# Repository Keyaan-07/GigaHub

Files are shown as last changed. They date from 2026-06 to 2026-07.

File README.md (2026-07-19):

# GigaHub
GigaHub is a USB 3.0 Hub capable of speeds upto 5Gbps. It comes in a small form factor and can handle upto 4 devices simultaneously. The silkscreen on the bottom makes it obvious. You plug in the USB-C cable on one side, and you get 4x USB-C cables. 

I made this project just for fun and because i had some free time. I could've made USB 2.0 hub but this was a bit challenging thus i made this!!

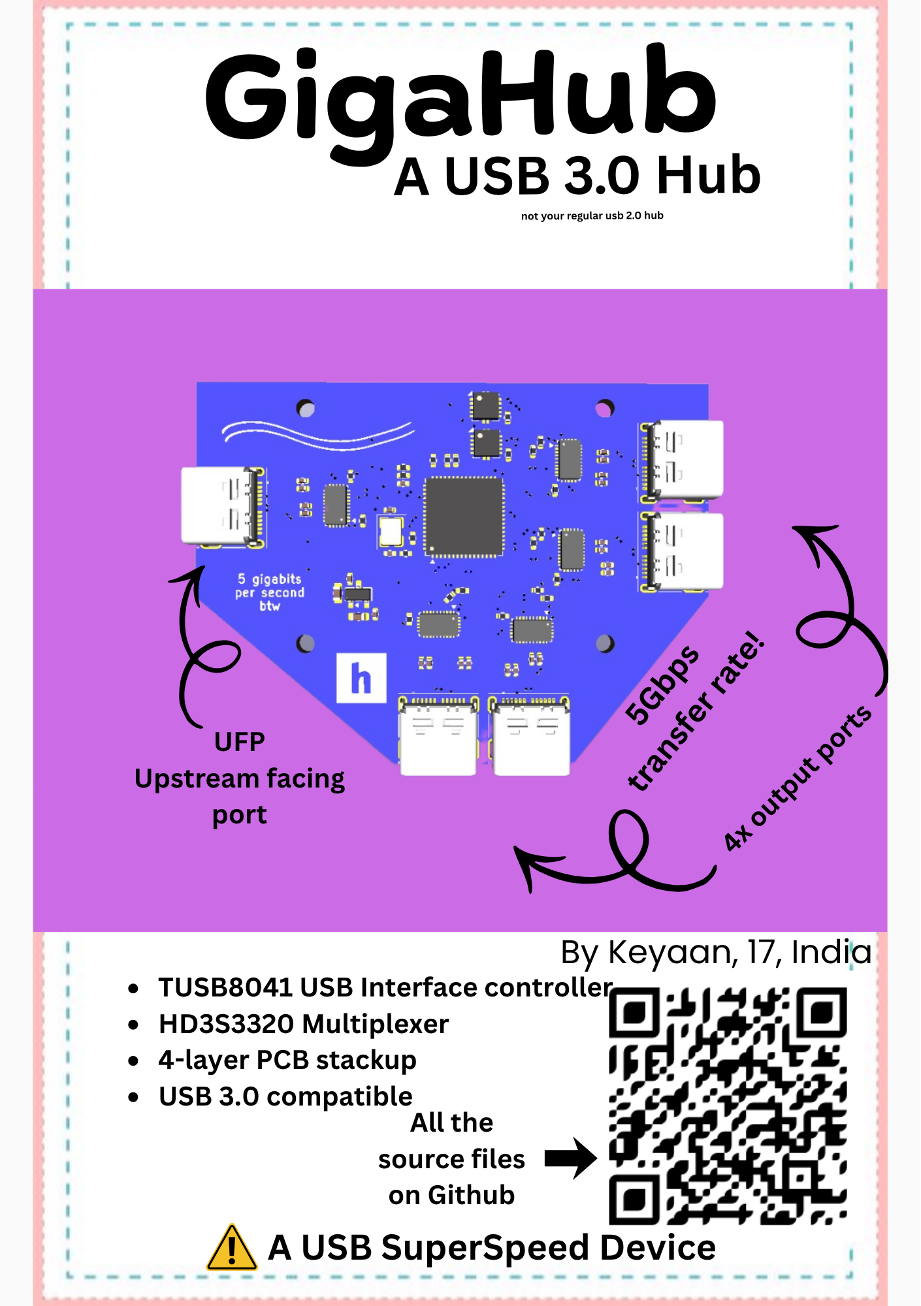
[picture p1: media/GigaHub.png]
zine magazine page
  
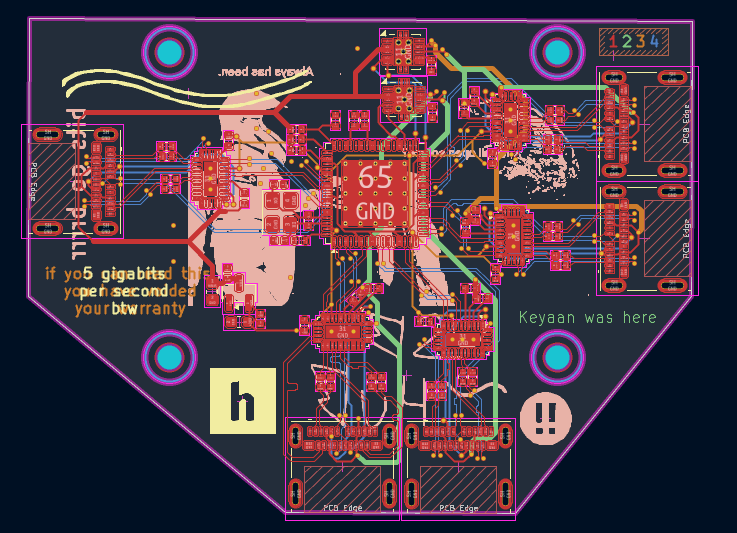
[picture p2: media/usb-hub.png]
PCB
  
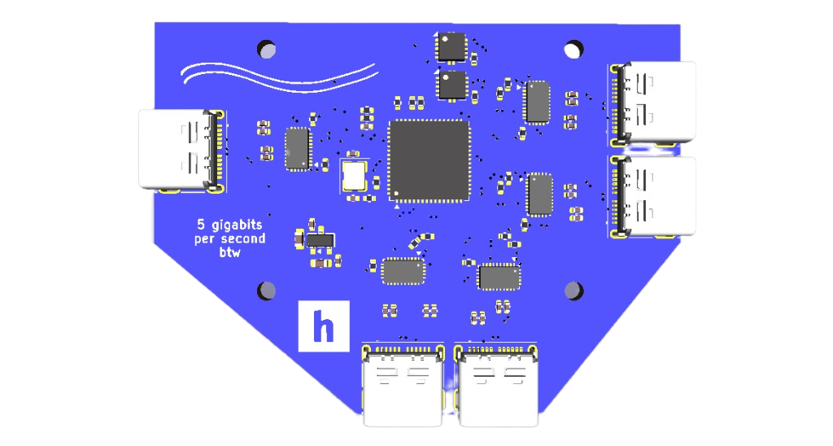
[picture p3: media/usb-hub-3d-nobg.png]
3d
  
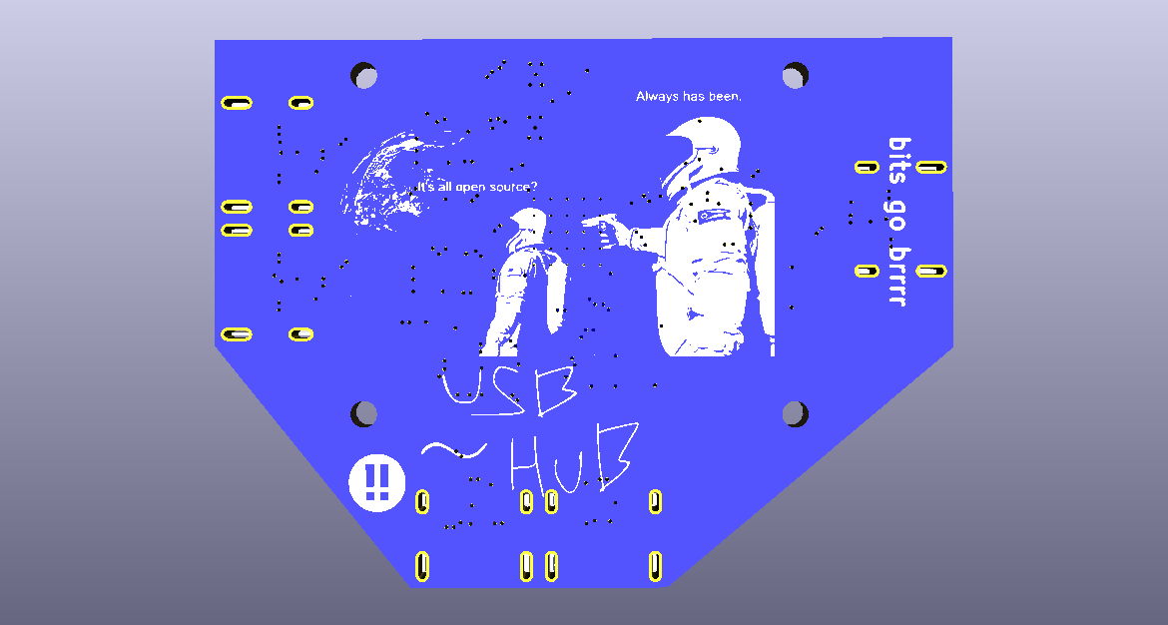
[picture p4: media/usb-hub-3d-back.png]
3d-back
  
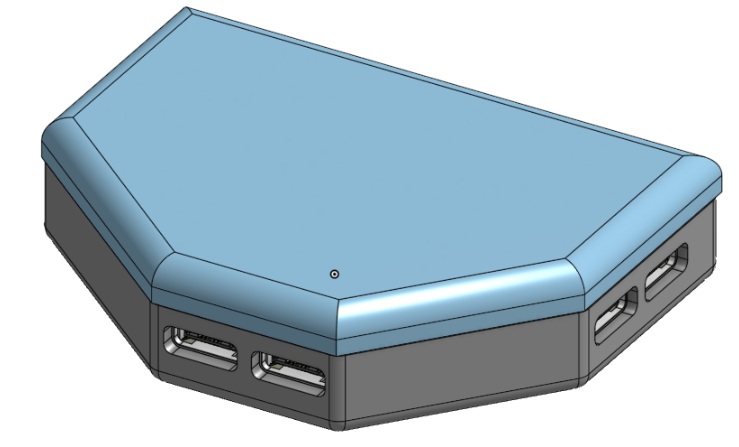
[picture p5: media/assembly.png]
assembly
  
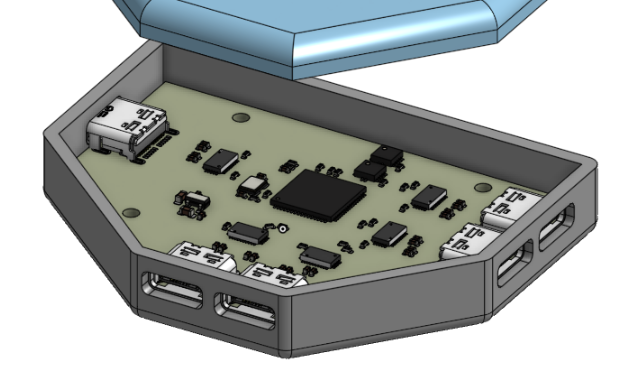
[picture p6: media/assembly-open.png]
assembly
  
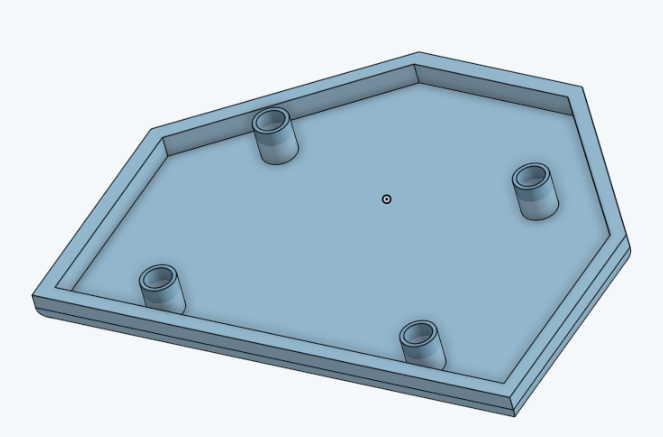
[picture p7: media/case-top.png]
top case
  
schematic  

[Onshape link](https://cad.onshape.com/documents/e81256595efe5e6b347fe7a8/w/0dcc8df7d91fb49fe0a745b9/e/4c090b9e2a0ff4ca85e35435)  
[Kicanvas link](https://kicanvas.org/?github=https://github.com/Keyaan-07/GigaHub/tree/main/hardware)  

# How to build

To Assemble this PCB, first you need to be familiar with soldering. You take your bare PCB, apply solder paste on it(soldering iron and solder is not recommended because it involves pins under the surface, such as the USB-C receptacles). Then, you take a hotplate or a hot air gun and melt the solder appropriately. There are many tutorials online teaching it in a great way, go search there!

The linked html file under /hardware/bom helps you with placement!

# BOM
|Designator |Function |Value |Footprint |Quantity |Price |Amount |Order|Note |Link |
|---|---|---|---|---|---|---|-----|---|---|
|PCB |PCB |4 layer board |49.57mm x 34.54mm |5 |0.4 |2 |Yes  | |https://jlcpcb.com/ |
|C1, C10, C11, C2, C3, C4, C5, C6, C7, C8, C9 |Capacitor |100n |402 |11 |0.0077|0.0847 |No | |https://www.lcsc.com/product-detail/C426067.html  |
|C12, C13 |Capacitor |15p |402 |50 |0.019 |0.95 |Yes  |50 is MOQ |https://www.lcsc.com/product-detail/C441742.html  |
|J1, J2, J3, J4, J5 |Receptacle |USB_C_Receptacle|USB_C_Receptacle_Molex_105450-0101 |5 |0.29  |1.45 |Yes  | |https://www.lcsc.com/product-detail/C48887178.html|
|R1 |Resistor |9.53k |402 |100 |0.0008|0.08 |Yes  |100 is MOQ|https://www.lcsc.com/product-detail/C96273.html |
|R2, R3, R4, R10, R11, R12, R13, R14, R15, R16, R17, R18, R19|Resistor |5.1k |402 |13 |0.0056|0.0728 |No | |https://www.lcsc.com/product-detail/C278598.html  |
|R5 |Resistor |10k |402 |100 |0.0006|0.06 |Yes  |100 is MOQ|https://www.lcsc.com/product-detail/C3020235.html |
|R6 |Resistor |90.9k |402 |100 |0.0006|0.06 |Yes  |100 is MOQ|https://www.lcsc.com/product-detail/C2998102.html |
|R7 |Resistor |1M |402 |100 |0.0009|0.09 |Yes  |100 is MOQ|https://www.lcsc.com/product-detail/C138033.html  |
|R8, R9 |Resistor |30k |402 |100 |0.0007|0.07 |Yes  |100 is MOQ|https://www.lcsc.com/product-detail/C2909347.html |
|U1 |Hub Controller IC|TUSB8041 |QFN-64-1EP_9x9mm_P0.5mm_EP6x6mm_ThermalVias |1 |4.83  |4.83 |Yes  | |https://www.lcsc.com/product-detail/C544686.html  |
|U4, U5, U7, U7, U8 |Multiplexer IC |HD3SS3220 |QFN-30-1EP |5 |1.89  |9.44 |Yes  | |https://www.lcsc.com/product-detail/C165155.html  |
|U2, U3 |Power switch |TPS2561 |VSON-10-1EP_3x3mm_P0.5mm_EP1.65x2.4mm_ThermalVias|2 |0.8 |1.6 |Yes  | |https://www.lcsc.com/product-detail/C140303.html  |
|Y1 |Crystal |24 MHz |Crystal_SMD_3225-4Pin_3.2x2.5mm |10 |0.036 |0.36 |Yes  |10 is MOQ |https://www.lcsc.com/product-detail/C41383243.html|
| | | | |Shipping fee JLC | |7.72 | | | |
| | | | |Shipping fee LCSC| |3.92 | | | |
| | | | |Handling Fee LCSC| |3 | | | |
| | | | |Total | |35.7875| | | |

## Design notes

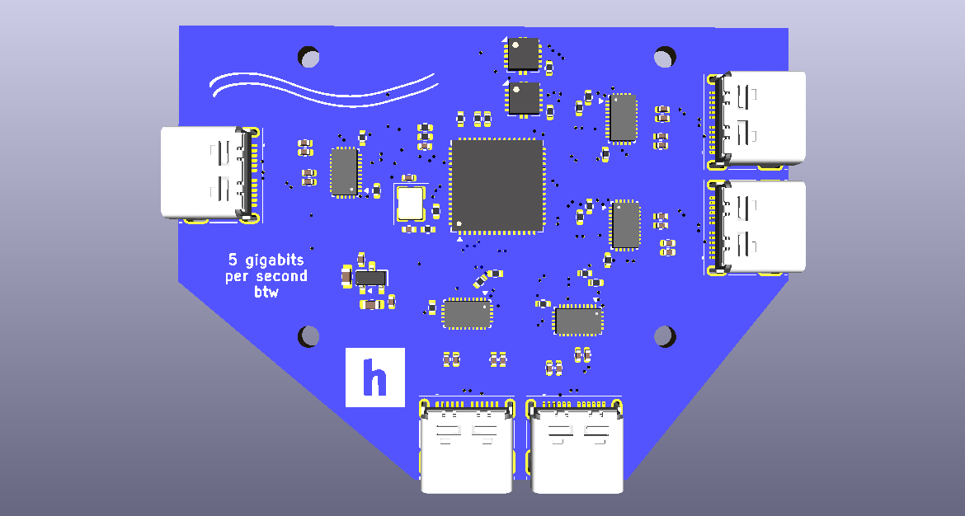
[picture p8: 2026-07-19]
media/usb-hub-3d.png

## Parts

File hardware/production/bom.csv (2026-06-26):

Designator | Footprint | Quantity | Value | LCSC Part #
C1, C11, C14, C15, C16, C17, C18, C19, C2, C20, C21, C22, C23, C24, C25, C26, C27, C28, C29, C3, C4, C6, C7 | 0402 | 23 | 100n
C12, C13 | 0402 | 2 | C_Small
C5, C8 | 0603 | 2 | 10u
J1, J2, J3, J4, J5 | USB_C_Receptacle_Molex_105450-0101 | 5 | USB_C_Receptacle
R1 | 0402 | 1 | 9.53k
R10, R11, R12, R13, R5 | 0402 | 5 | 10k
R2, R3, R4 | 0402 | 3 | 4.7k
R20, R21, R25, R27, R29 | 0402 | 5 | 100k
R22, R23, R24, R26, R28 | 0402 | 5 | 900k
R6 | 0402 | 1 | 90.9k
R7 | 0402 | 1 | 1M
R8, R9 | 0402 | 2 | 30k
U1 | QFN-64-1EP_9x9mm_P0.5mm_EP6x6mm_ThermalVias | 1 | TUSB8041
U2, U3 | VSON-10-1EP_3x3mm_P0.5mm_EP1.65x2.4mm_ThermalVias | 2 | TPS2561
U4, U5, U7, U8, U9 | Texas_RNH0030A_WQFN-30-1EP_2.5x4.5mm_P0.4mm_EP1.2x3.2mm | 5 | HD3S3220
U6 | SOT-23 | 1 | MCP1700x-330xxTT
Y1 | Crystal_SMD_3225-4Pin_3.2x2.5mm | 1 | Crystal_GND24

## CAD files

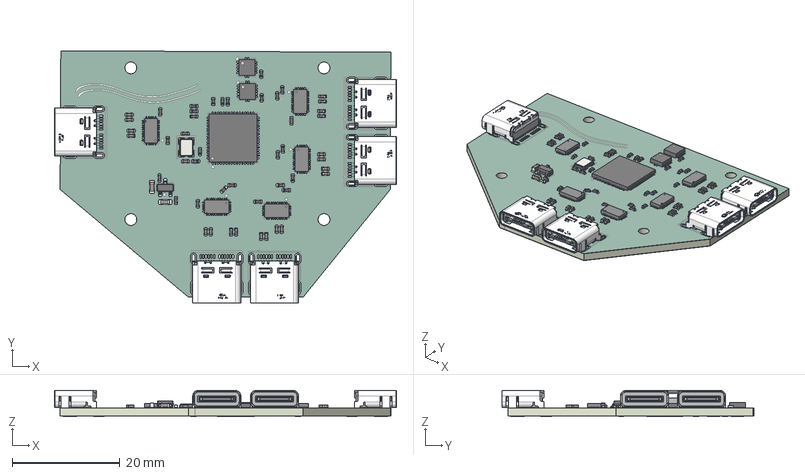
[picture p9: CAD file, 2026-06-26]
CAD/GigaHub - PCB.step
63.5 x 46.9 x 4.83 mm
C_0402_1005Metric x 25
R_0402_1005Metric x 23
WQFN-30_L4.5-W2.5-P0.4-BL-EP x 5
USB-C-SMD_TYPE-C-USB-18 x 5
SOT-23
Crystal_SMD_3225-4Pin_3.2x2.5mm
VSON_10_1EP_3x3mm_Pitch05mm_ThermalPad x 2
C_0603_1608Metric x 2
QFN-64-1EP_9x9mm_P0.5mm_EP6x6mm
usb-hub_pad
usb-hub_silkscreen x 2
usb-hub_soldermask x 2
usb-hub_PCB

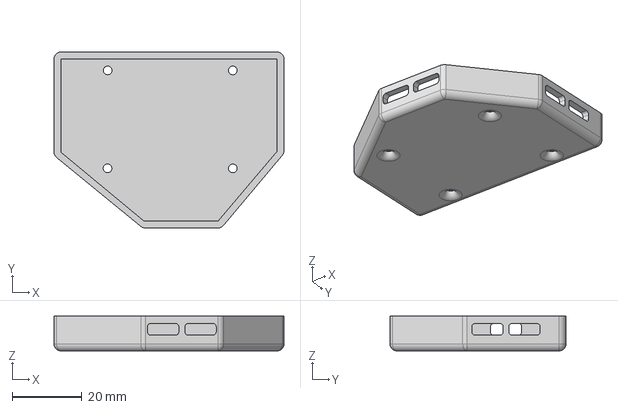
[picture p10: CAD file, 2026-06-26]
CAD/GigaHub - Bottom.step
66.0 x 50.5 x 10.0 mm

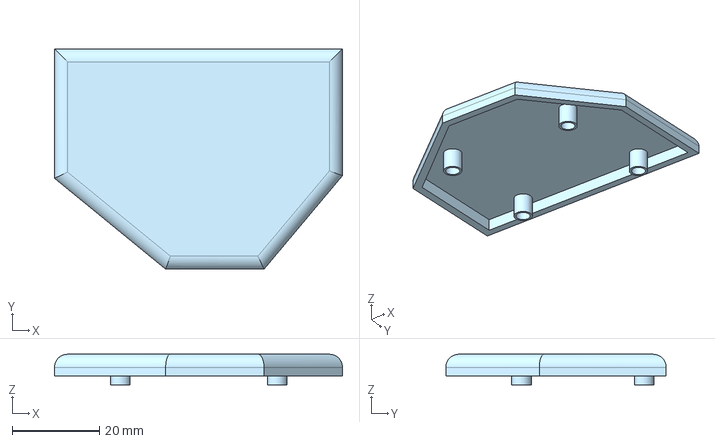
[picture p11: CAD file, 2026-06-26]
CAD/GigaHub - Top.step
66.0 x 50.5 x 7.00 mm

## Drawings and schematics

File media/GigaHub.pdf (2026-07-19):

# A USB 3.0 Hub

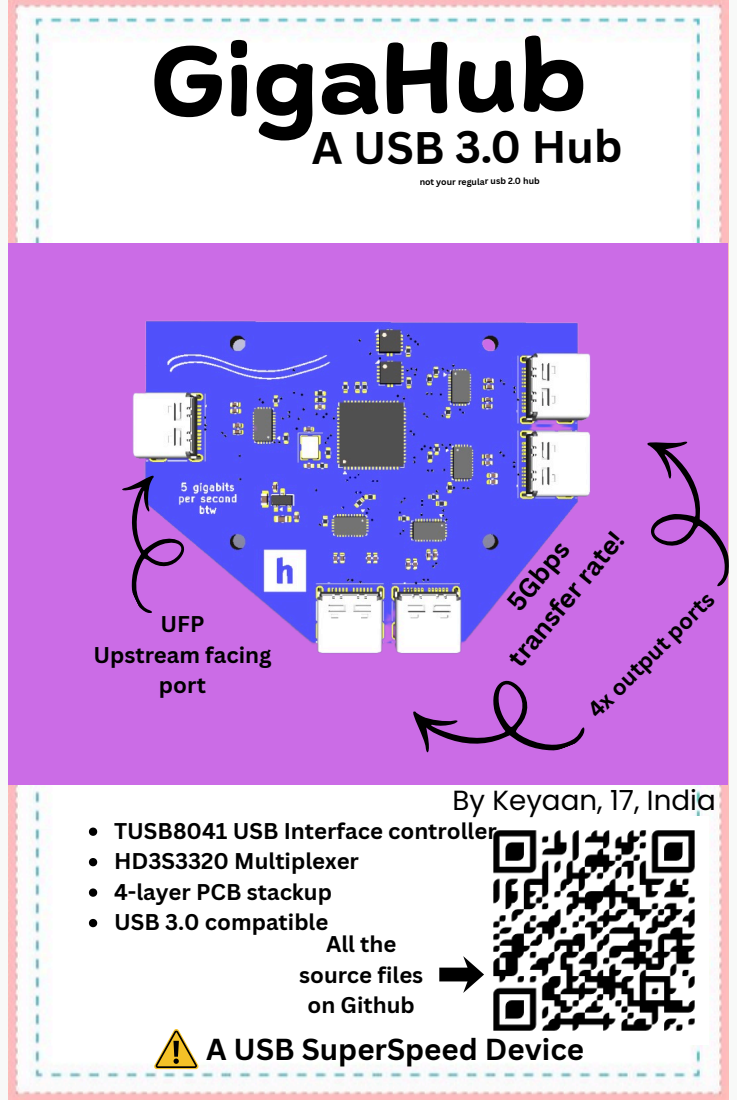
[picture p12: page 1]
5Gbps; transfer rate!; UFP Upstream facing port; GigaHub; 4x output ports

not your regular usb 2.0 hub

By Keyaan, 17, India

TUSB8041 USB Interface controller
HD3S3320 Multiplexer
4-layer PCB stackup
USB 3.0 compatible

All the
source files
on Github
A USB SuperSpeed Device

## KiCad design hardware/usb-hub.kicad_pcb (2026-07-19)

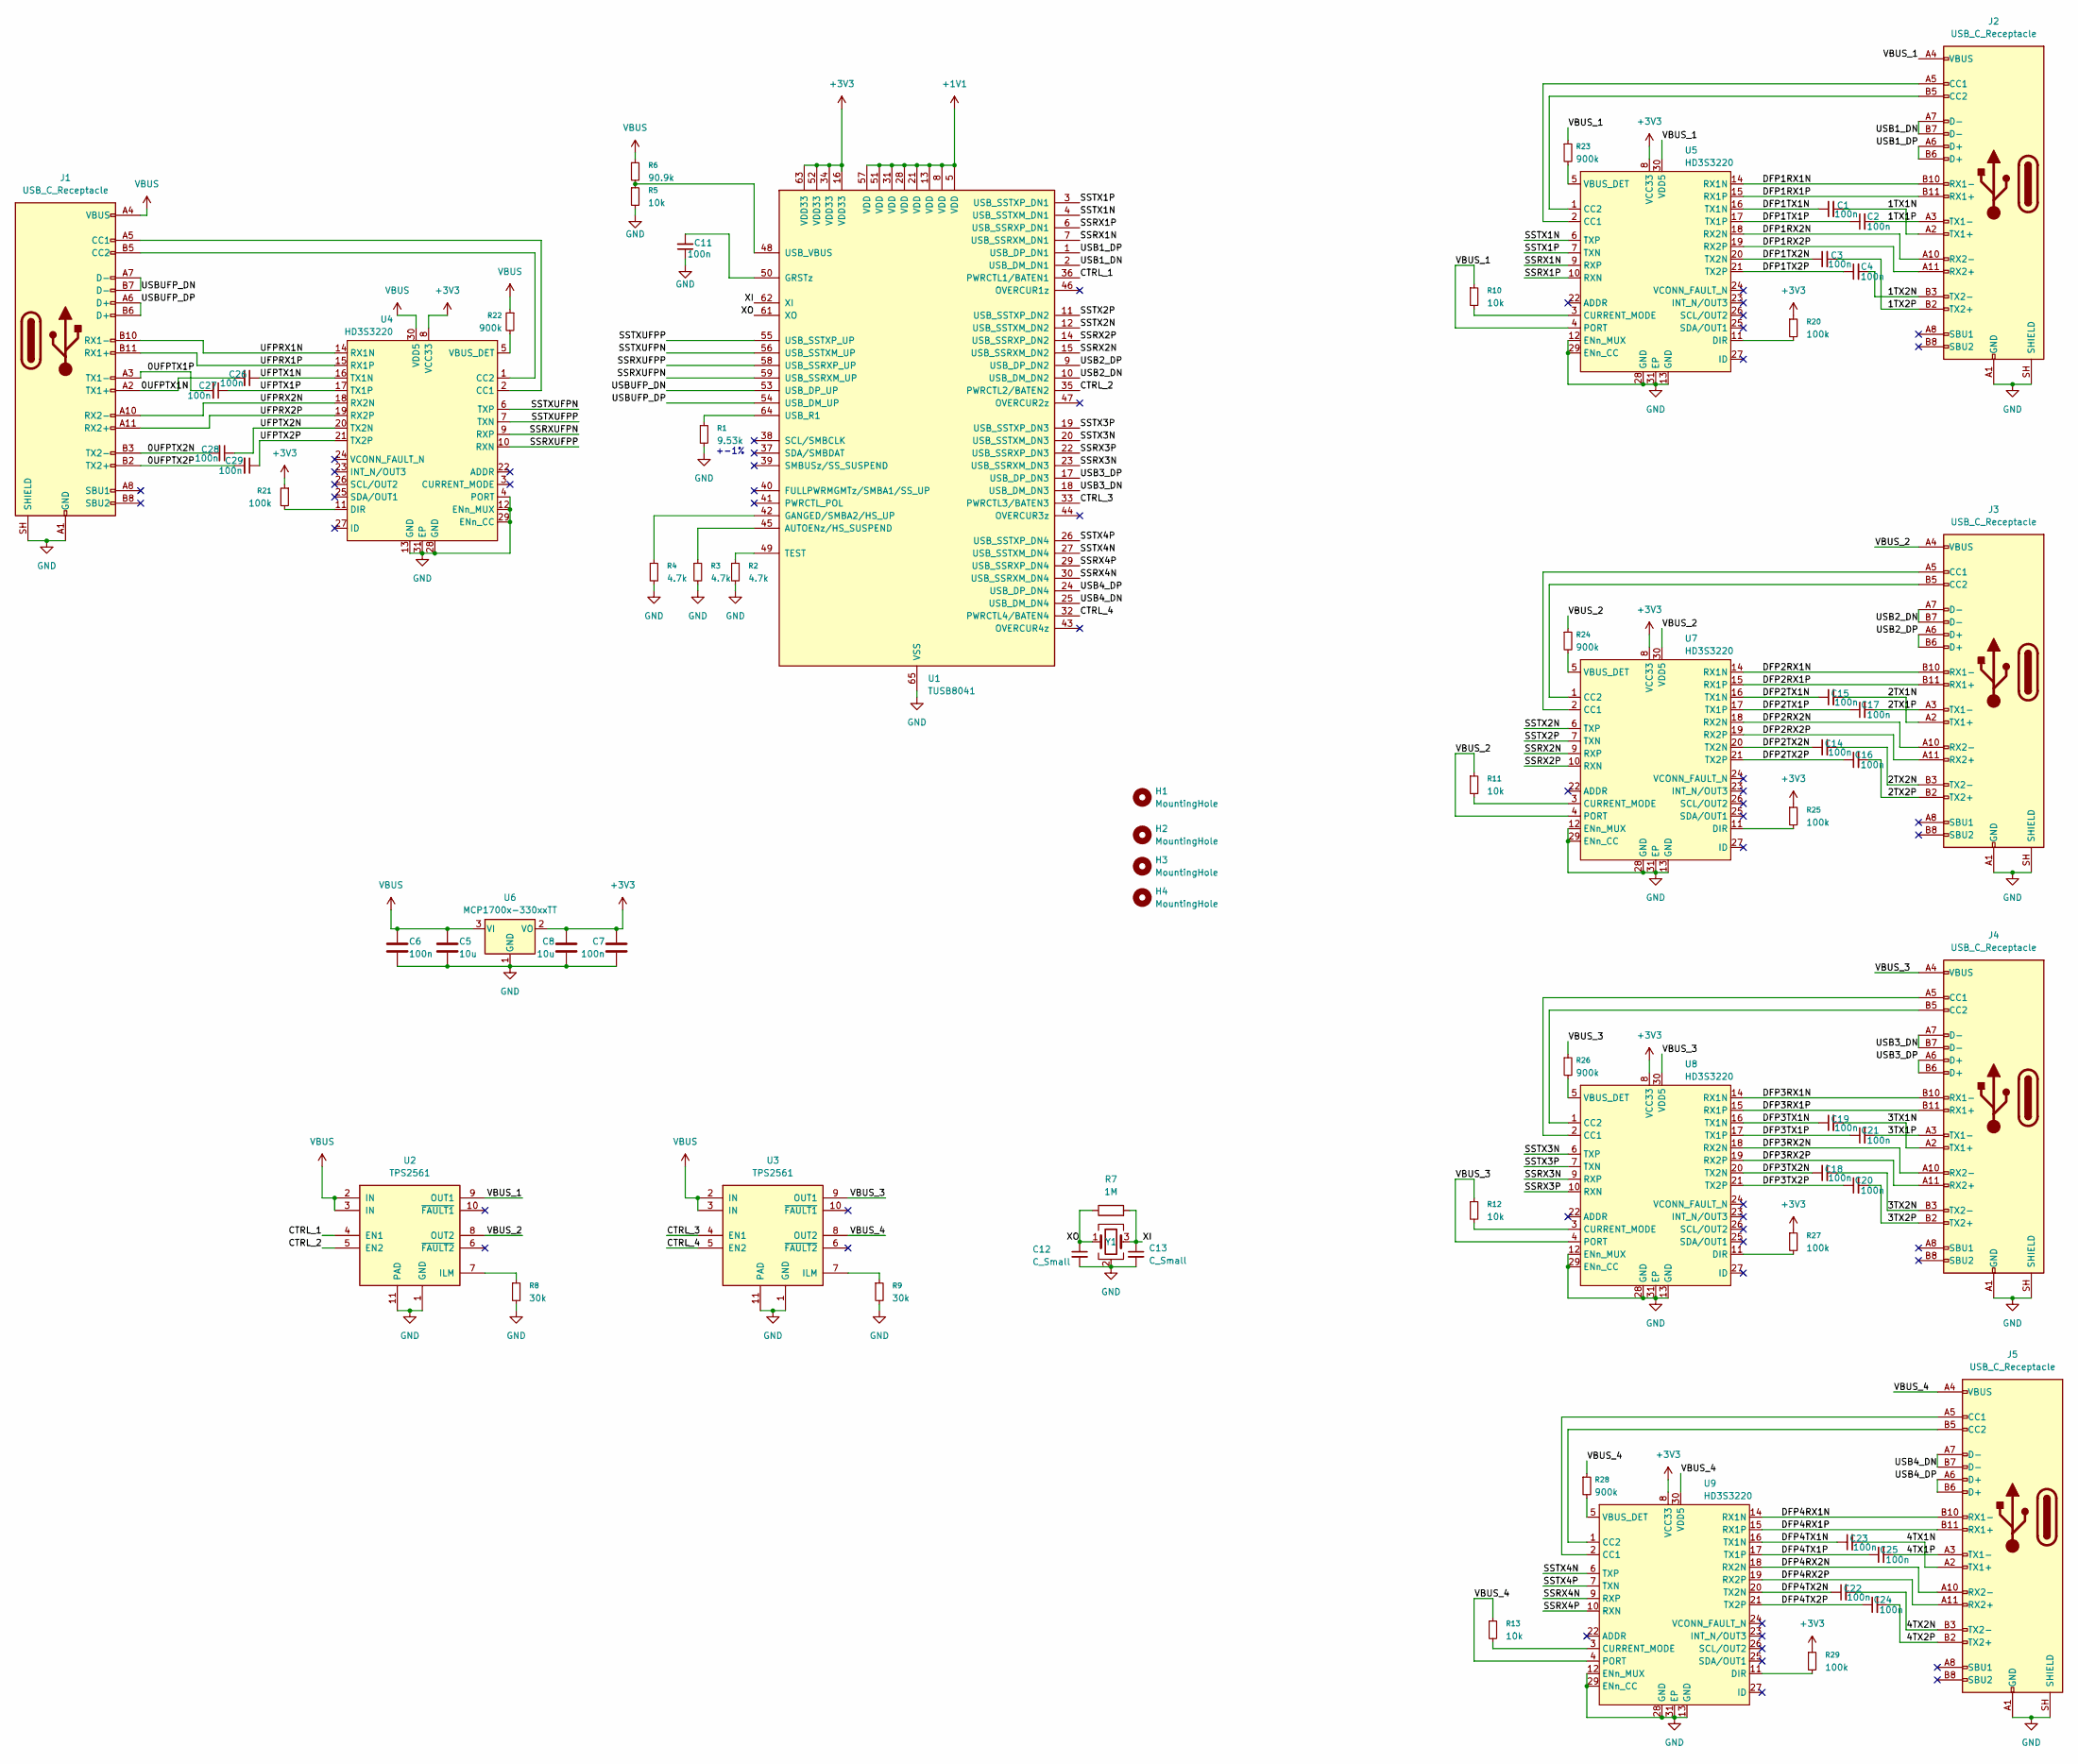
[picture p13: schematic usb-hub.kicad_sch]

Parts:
C1, C2, C3, C4, C6, C7, C11, C14, C15, C16, C17, C18, C19, C20, C21, C22, C23, C24, C25, C26, C27, C28, C29: 100n; C_0402_1005Metric
C5, C8: 10u; C_0603_1608Metric
C12, C13: C_Small; C_0402_1005Metric
H1, H2, H3, H4: MountingHole; MountingHole_2.2mm_M2
J1, J2, J3, J4, J5: USB_C_Receptacle; USB_C_Receptacle_Molex_105450-0101
R1: 9.53k; R_0402_1005Metric
R2, R3, R4: 4.7k; R_0402_1005Metric
R5, R10, R11, R12, R13: 10k; R_0402_1005Metric
R6: 90.9k; R_0402_1005Metric
R7: 1M; R_0402_1005Metric
R8, R9: 30k; R_0402_1005Metric
R20, R21, R25, R27, R29: 100k; R_0402_1005Metric
R22, R23, R24, R26, R28: 900k; R_0402_1005Metric
U1: TUSB8041; QFN-64-1EP_9x9mm_P0.5mm_EP6x6mm_ThermalVias
U2, U3: TPS2561; VSON-10-1EP_3x3mm_P0.5mm_EP1.65x2.4mm_ThermalVias
U4, U5, U7, U8, U9: HD3S3220; Texas_RNH0030A_WQFN-30-1EP_2.5x4.5mm_P0.4mm_EP1.2x3.2mm
U6: MCP1700x-330xxTT; SOT-23
Y1: Crystal_GND24; Crystal_SMD_3225-4Pin_3.2x2.5mm

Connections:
+1V1: U1.5 (VDD), U1.8 (VDD), U1.13 (VDD), U1.21 (VDD), U1.28 (VDD), U1.31 (VDD), U1.51 (VDD), U1.57 (VDD)
+3V3: C7.1, C8.1, R20.1, R21.1, R25.1, R27.1, R29.1, U1.16 (VDD33), U1.34 (VDD33), U1.52 (VDD33), U1.63 (VDD33), U4.8 (VCC33), U5.8 (VCC33), U6.2 (VO), U7.8 (VCC33), U8.8 (VCC33), U9.8 (VCC33)
/0UFPTX1N: C26.2, J1.A2 (TX1+)
/0UFPTX1P: C27.2, J1.A3 (TX1-)
/0UFPTX2N: C28.2, J1.B3 (TX2-)
/0UFPTX2P: C29.2, J1.B2 (TX2+)
/1TX1N: C1.2, J2.A2 (TX1+)
/1TX1P: C2.2, J2.A3 (TX1-)
/1TX2N: C4.2, J2.B3 (TX2-)
/1TX2P: C3.2, J2.B2 (TX2+)
/2TX1N: C15.2, J3.A2 (TX1+)
/2TX1P: C17.2, J3.A3 (TX1-)
/2TX2N: C14.2, J3.B3 (TX2-)
/2TX2P: C16.2, J3.B2 (TX2+)
/3TX1N: C19.2, J4.A2 (TX1+)
/3TX1P: C21.2, J4.A3 (TX1-)
/3TX2N: C18.2, J4.B3 (TX2-)
/3TX2P: C20.2, J4.B2 (TX2+)
/4TX1N: C23.2, J5.A2 (TX1+)
/4TX1P: C25.2, J5.A3 (TX1-)
/4TX2N: C22.2, J5.B3 (TX2-)
/4TX2P: C24.2, J5.B2 (TX2+)
/CTRL_1: U1.36 (PWRCTL1/BATEN1), U2.4 (EN1)
/CTRL_2: U1.35 (PWRCTL2/BATEN2), U2.5 (EN2)
/CTRL_3: U1.33 (PWRCTL3/BATEN3), U3.4 (EN1)
/CTRL_4: U1.32 (PWRCTL4/BATEN4), U3.5 (EN2)
/DFP1RX1N: J2.B10 (RX1-), U5.14 (RX1N)
/DFP1RX1P: J2.B11 (RX1+), U5.15 (RX1P)
/DFP1RX2N: J2.A10 (RX2-), U5.18 (RX2N)
/DFP1RX2P: J2.A11 (RX2+), U5.19 (RX2P)
/DFP1TX1N: C1.1, U5.16 (TX1N)
/DFP1TX1P: C2.1, U5.17 (TX1P)
/DFP1TX2N: C3.1, U5.20 (TX2N)
/DFP1TX2P: C4.1, U5.21 (TX2P)
/DFP2RX1N: J3.B10 (RX1-), U7.14 (RX1N)
/DFP2RX1P: J3.B11 (RX1+), U7.15 (RX1P)
/DFP2RX2N: J3.A10 (RX2-), U7.18 (RX2N)
/DFP2RX2P: J3.A11 (RX2+), U7.19 (RX2P)
/DFP2TX1N: C15.1, U7.16 (TX1N)
/DFP2TX1P: C17.1, U7.17 (TX1P)
/DFP2TX2N: C14.1, U7.20 (TX2N)
/DFP2TX2P: C16.1, U7.21 (TX2P)
/DFP3RX1N: J4.B10 (RX1-), U8.14 (RX1N)
/DFP3RX1P: J4.B11 (RX1+), U8.15 (RX1P)
/DFP3RX2N: J4.A10 (RX2-), U8.18 (RX2N)
/DFP3RX2P: J4.A11 (RX2+), U8.19 (RX2P)
/DFP3TX1N: C19.1, U8.16 (TX1N)
/DFP3TX1P: C21.1, U8.17 (TX1P)
/DFP3TX2N: C18.1, U8.20 (TX2N)
/DFP3TX2P: C20.1, U8.21 (TX2P)
/DFP4RX1N: J5.B10 (RX1-), U9.14 (RX1N)
/DFP4RX1P: J5.B11 (RX1+), U9.15 (RX1P)
/DFP4RX2N: J5.A10 (RX2-), U9.18 (RX2N)
/DFP4RX2P: J5.A11 (RX2+), U9.19 (RX2P)
/DFP4TX1N: C23.1, U9.16 (TX1N)
/DFP4TX1P: C25.1, U9.17 (TX1P)
/DFP4TX2N: C22.1, U9.20 (TX2N)
/DFP4TX2P: C24.1, U9.21 (TX2P)
/SSRX1N: U1.7 (USB_SSRXM_DN1), U5.9 (RXP)
/SSRX1P: U1.6 (USB_SSRXP_DN1), U5.10 (RXN)
/SSRX2N: U1.15 (USB_SSRXM_DN2), U7.9 (RXP)
/SSRX2P: U1.14 (USB_SSRXP_DN2), U7.10 (RXN)
/SSRX3N: U1.23 (USB_SSRXM_DN3), U8.9 (RXP)
/SSRX3P: U1.22 (USB_SSRXP_DN3), U8.10 (RXN)
/SSRX4N: U1.30 (USB_SSRXM_DN4), U9.9 (RXP)
/SSRX4P: U1.29 (USB_SSRXP_DN4), U9.10 (RXN)
/SSRXUFPN: U1.59 (USB_SSRXM_UP), U4.9 (RXP)
/SSRXUFPP: U1.58 (USB_SSRXP_UP), U4.10 (RXN)
/SSTX1N: U1.4 (USB_SSTXM_DN1), U5.6 (TXP)
/SSTX1P: U1.3 (USB_SSTXP_DN1), U5.7 (TXN)
/SSTX2N: U1.12 (USB_SSTXM_DN2), U7.6 (TXP)
/SSTX2P: U1.11 (USB_SSTXP_DN2), U7.7 (TXN)
/SSTX3N: U1.20 (USB_SSTXM_DN3), U8.6 (TXP)
/SSTX3P: U1.19 (USB_SSTXP_DN3), U8.7 (TXN)
/SSTX4N: U1.27 (USB_SSTXM_DN4), U9.6 (TXP)
/SSTX4P: U1.26 (USB_SSTXP_DN4), U9.7 (TXN)
/SSTXUFPN: U1.56 (USB_SSTXM_UP), U4.6 (TXP)
/SSTXUFPP: U1.55 (USB_SSTXP_UP), U4.7 (TXN)
/UFPRX1N: J1.B10 (RX1-), U4.14 (RX1N)
/UFPRX1P: J1.B11 (RX1+), U4.15 (RX1P)
/UFPRX2N: J1.A10 (RX2-), U4.18 (RX2N)
/UFPRX2P: J1.A11 (RX2+), U4.19 (RX2P)
/UFPTX1N: C26.1, U4.16 (TX1N)
/UFPTX1P: C27.1, U4.17 (TX1P)
/UFPTX2N: C28.1, U4.20 (TX2N)
/UFPTX2P: C29.1, U4.21 (TX2P)
/USB1_DN: J2.A7 (D-), J2.B7 (D-), U1.2 (USB_DM_DN1)
/USB1_DP: J2.A6 (D+), J2.B6 (D+), U1.1 (USB_DP_DN1)
/USB2_DN: J3.A7 (D-), J3.B7 (D-), U1.10 (USB_DM_DN2)
/USB2_DP: J3.A6 (D+), J3.B6 (D+), U1.9 (USB_DP_DN2)
/USB3_DN: J4.A7 (D-), J4.B7 (D-), U1.18 (USB_DM_DN3)
/USB3_DP: J4.A6 (D+), J4.B6 (D+), U1.17 (USB_DP_DN3)
/USB4_DN: J5.A7 (D-), J5.B7 (D-), U1.25 (USB_DM_DN4)
/USB4_DP: J5.A6 (D+), J5.B6 (D+), U1.24 (USB_DP_DN4)
/USBUFP_DN: J1.A7 (D-), J1.B7 (D-), U1.53 (USB_DP_UP)
/USBUFP_DP: J1.A6 (D+), J1.B6 (D+), U1.54 (USB_DM_UP)
/VBUS_1: J2.A4 (VBUS), J2.A9 (VBUS), J2.B4 (VBUS), J2.B9 (VBUS), R10.1, R23.1, U2.9 (OUT1), U5.4 (PORT), U5.30 (VDD5)
/VBUS_2: J3.A4 (VBUS), J3.A9 (VBUS), J3.B4 (VBUS), J3.B9 (VBUS), R11.1, R24.1, U2.8 (OUT2), U7.4 (PORT), U7.30 (VDD5)
/VBUS_3: J4.A4 (VBUS), J4.A9 (VBUS), J4.B4 (VBUS), J4.B9 (VBUS), R12.1, R26.1, U3.9 (OUT1), U8.4 (PORT), U8.30 (VDD5)
/VBUS_4: J5.A4 (VBUS), J5.A9 (VBUS), J5.B4 (VBUS), J5.B9 (VBUS), R13.1, R28.1, U3.8 (OUT2), U9.4 (PORT), U9.30 (VDD5)
/XI: C13.1, R7.2, U1.62 (XI), Y1.3
/XO: C12.1, R7.1, U1.61 (XO), Y1.1
GND: C5.2, C6.2, C7.2, C8.2, C11.1, C12.2, C13.2, J1.A1 (GND), J1.A12 (GND), J1.B1 (GND), J1.B12 (GND), J1.SH (SHIELD), J2.A1 (GND), J2.A12 (GND), J2.B1 (GND), J2.B12 (GND), J2.SH (SHIELD), J3.A1 (GND), J3.A12 (GND), J3.B1 (GND), J3.B12 (GND), J3.SH (SHIELD), J4.A1 (GND), J4.A12 (GND), J4.B1 (GND), J4.B12 (GND), J4.SH (SHIELD), J5.A1 (GND), J5.A12 (GND), J5.B1 (GND), J5.B12 (GND), J5.SH (SHIELD), R1.2, R2.2, R3.2, R4.2, R5.2, R8.2, R9.2, U1.65 (VSS), U2.1 (GND), U2.11 (PAD), U3.1 (GND), U3.11 (PAD), U4.4 (PORT), U4.12 (ENn_MUX), U4.13 (GND), U4.28 (GND), U4.29 (ENn_CC), U4.31 (EP), U5.12 (ENn_MUX), U5.13 (GND), U5.28 (GND), U5.29 (ENn_CC), U5.31 (EP), U6.1 (GND), U7.12 (ENn_MUX), U7.13 (GND), U7.28 (GND), U7.29 (ENn_CC), U7.31 (EP), U8.12 (ENn_MUX), U8.13 (GND), U8.28 (GND), U8.29 (ENn_CC), U8.31 (EP), U9.12 (ENn_MUX), U9.13 (GND), U9.28 (GND), U9.29 (ENn_CC), U9.31 (EP), Y1.2 (G), Y1.4 (G)
unnamed: J1.A5 (CC1), U4.2 (CC1)
unnamed: J1.B5 (CC2), U4.1 (CC2)
unnamed: J2.A5 (CC1), U5.2 (CC1)
unnamed: J2.B5 (CC2), U5.1 (CC2)
unnamed: J3.A5 (CC1), U7.2 (CC1)
unnamed: J3.B5 (CC2), U7.1 (CC2)
unnamed: J4.A5 (CC1), U8.2 (CC1)
unnamed: J4.B5 (CC2), U8.1 (CC2)
unnamed: J5.A5 (CC1), U9.2 (CC1)
unnamed: J5.B5 (CC2), U9.1 (CC2)
unnamed: R3.1, U1.45 (AUTOENz/HS_SUSPEND)
unnamed: R4.1, U1.42 (GANGED/SMBA2/HS_UP)
unnamed: C11.2, U1.50 (GRSTz)
unnamed: R2.1, U1.49 (TEST)
unnamed: R1.1, U1.64 (USB_R1)
unnamed: R5.1, R6.2, U1.48 (USB_VBUS)
unnamed: R8.1, U2.7 (ILM)
unnamed: R9.1, U3.7 (ILM)
unnamed: R21.2, U4.11 (DIR)
unnamed: R22.2, U4.5 (VBUS_DET)
unnamed: R10.2, U5.3 (CURRENT_MODE)
unnamed: R20.2, U5.11 (DIR)
unnamed: R23.2, U5.5 (VBUS_DET)
unnamed: R11.2, U7.3 (CURRENT_MODE)
unnamed: R25.2, U7.11 (DIR)
unnamed: R24.2, U7.5 (VBUS_DET)
unnamed: R12.2, U8.3 (CURRENT_MODE)
unnamed: R27.2, U8.11 (DIR)
unnamed: R26.2, U8.5 (VBUS_DET)
unnamed: R13.2, U9.3 (CURRENT_MODE)
unnamed: R29.2, U9.11 (DIR)
unnamed: R28.2, U9.5 (VBUS_DET)
VBUS: C5.1, C6.1, J1.A4 (VBUS), J1.A9 (VBUS), J1.B4 (VBUS), J1.B9 (VBUS), R6.1, R22.1, U2.2 (IN), U2.3 (IN), U3.2 (IN), U3.3 (IN), U4.30 (VDD5), U6.3 (VI)

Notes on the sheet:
+-1%

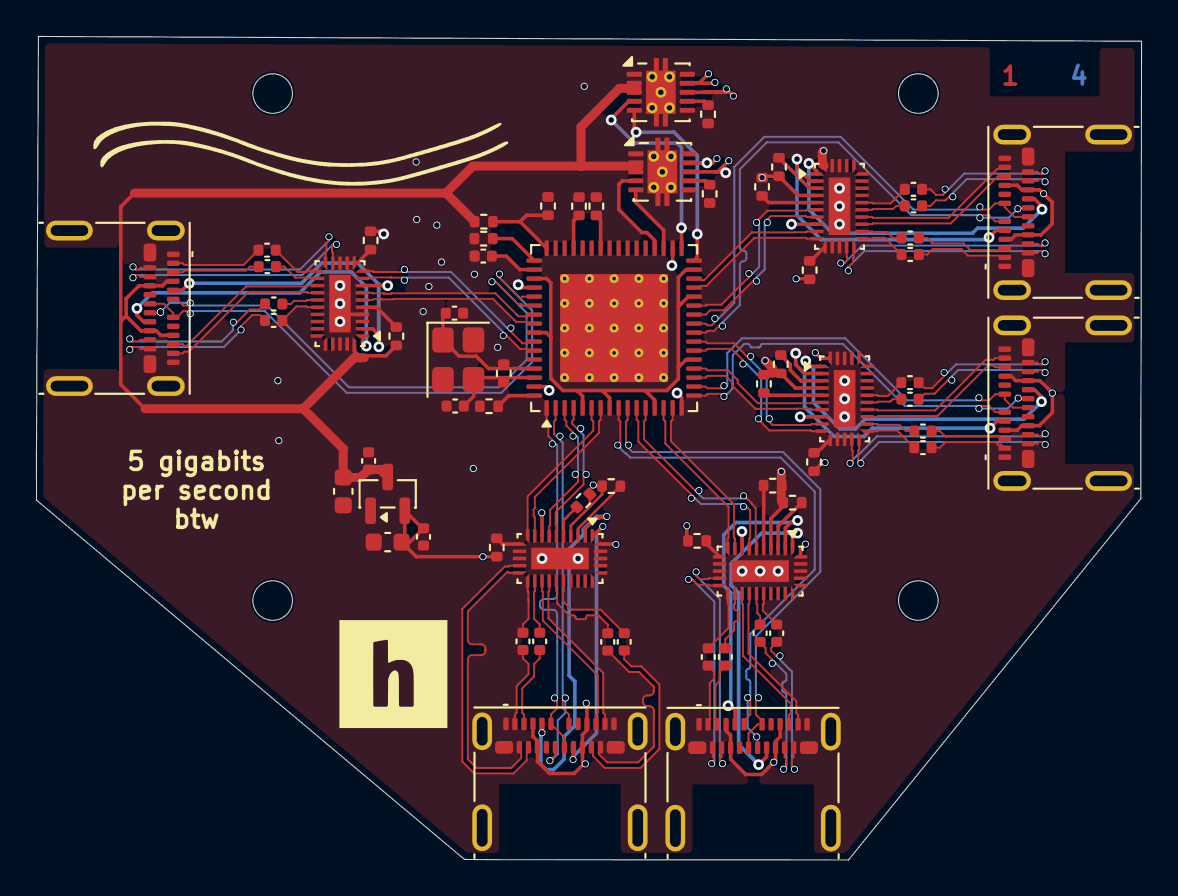
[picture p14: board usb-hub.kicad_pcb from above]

Board: 4 copper layers, 61.4 x 45.8 mm, 69 parts (0 on the bottom side), 136 nets.

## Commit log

2026-05-18 Hello World
    [usb-hub.kicad_pcb, usb-hub.kicad_sch]
2026-05-20 Bill of Materials
    [bom.csv]
2026-05-20 final files
    [usb-hub.kicad_pcb]
2026-05-20 Soldering info
2026-06-26 PCB Changed
    [usb-hub.kicad_pcb, usb-hub.kicad_sch]
2026-06-26 updated BOM
    [bom.csv]
2026-06-26 update BOM
2026-06-26 add CAD files for assembly
    [GigaHub - Bottom.step, GigaHub - PCB.step, GigaHub - Top.step]
2026-06-26 added schematic image
2026-06-26 add top case image
2026-06-26 added latest production files
    [bom.csv, designators.csv, positions.csv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]
2026-07-19 updated schematic image
2026-07-19 pcb updated
    [usb-hub.kicad_pcb]
